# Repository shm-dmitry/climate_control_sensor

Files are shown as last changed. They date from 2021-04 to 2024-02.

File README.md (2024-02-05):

Project info
=======

*DEPRECATED. New board/fw project in https://github.com/shm-dmitry/air-detector*

This module allows you to control climate in room.

It reports:
- CO2 value
- Temperature
- Humidity
- Pressure
- PMx value
- Illumination
- Direction and speed of air in ventilation  

It controls:
- Exhaust fan 
- Cooling fan with speed control (fan_pwm driver) 
- Control any device (except Air Conditioneers at now) via IR
- TION Breather (in development at now...) via Bluetooth

Additional features:
- Integrates with any smart-house system via MQTT protocol (over WIFI)
- Contains touchpad supports multi-click (single click, double click, tripple click etc)
- Contains RGB led to indicate some internal state you want



Project status
=======

Schematics is done.
Board is done.

| Sensor | Software | Hardware |
| --- | --- | --- |
| TION 3S | In progress | - |
| BME280 | OK | OK |
| SGP30 | OK | OK |
| BH1750 | OK | OK |
| MH-Z19B | OK | OK |
| PMS7003 | OK | OK |
| Internal ESP32 Touch Pin | OK | OK |
| RGB Led | OK | OK |
| FAN Switch control | OK | OK |
| FAN speed control | OK | OK |
| IR Transmitter | OK | OK |
| Anemometer | OK | OK |

Install guide
===========

Hardware:

1. Install EAGLE. Freeware version is OK: https://www.autodesk.com/products/eagle/free-download
2. Open board (lw_board.brd)
3. Generate CAM data and make order on any factory

Software
1. Install ESP-IDF SDK https://docs.espressif.com/projects/esp-idf/en/latest/esp32/get-started/index.html
2. Clone and open project. 
3. Open `sdkconfig` and setup project settings. You can enable or disable unused options in `Climate Control Configuration` menu.
4. Build and flash ESP32 Devkit

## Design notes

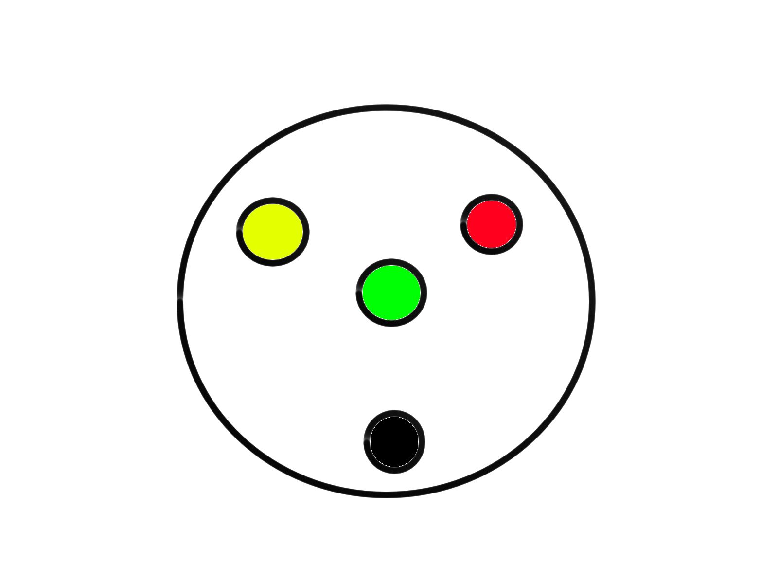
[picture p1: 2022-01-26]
anemometer_connector.jpg

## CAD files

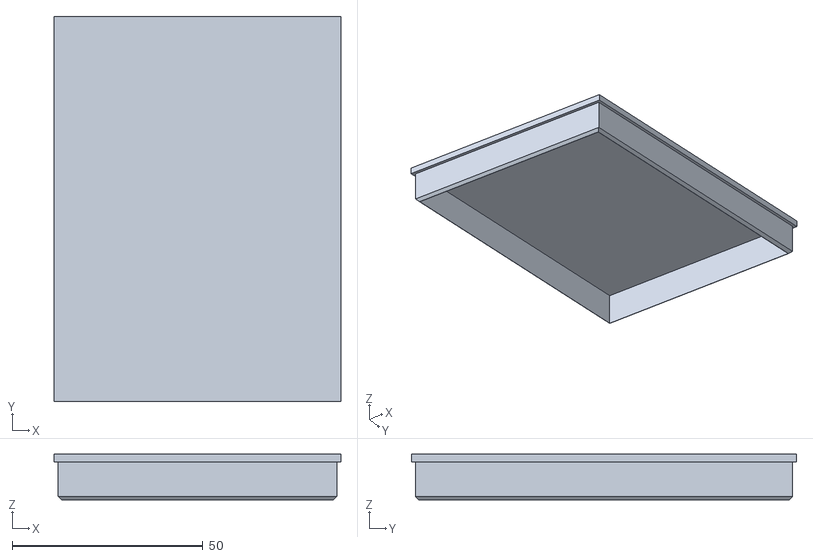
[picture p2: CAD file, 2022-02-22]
3d models/box-co2-hum-temp-tvoc-top.stl
75.2 x 101.0 x 12.0

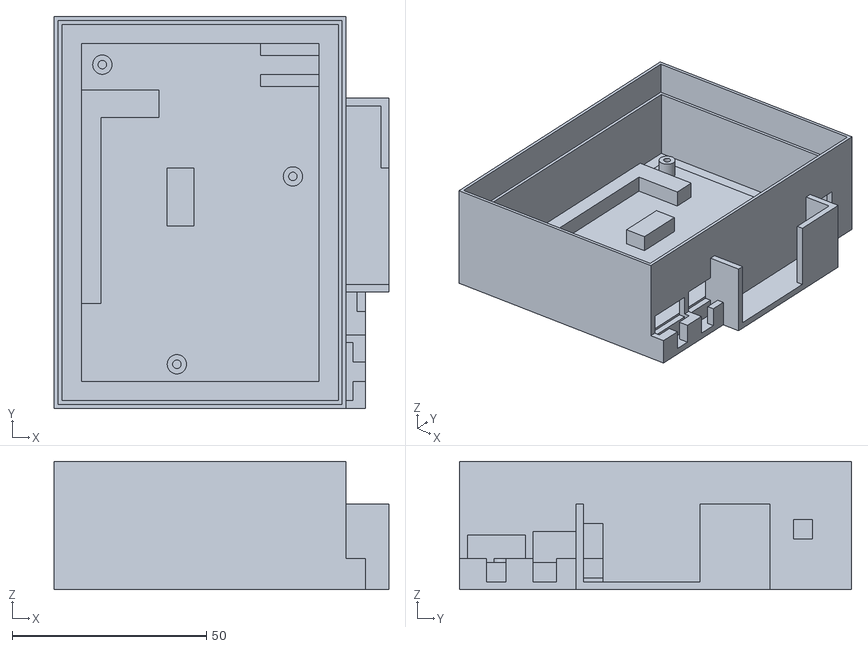
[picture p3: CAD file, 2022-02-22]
3d models/box-co2-hum-temp-tvoc-bottom.stl
86.2 x 101.0 x 33.0

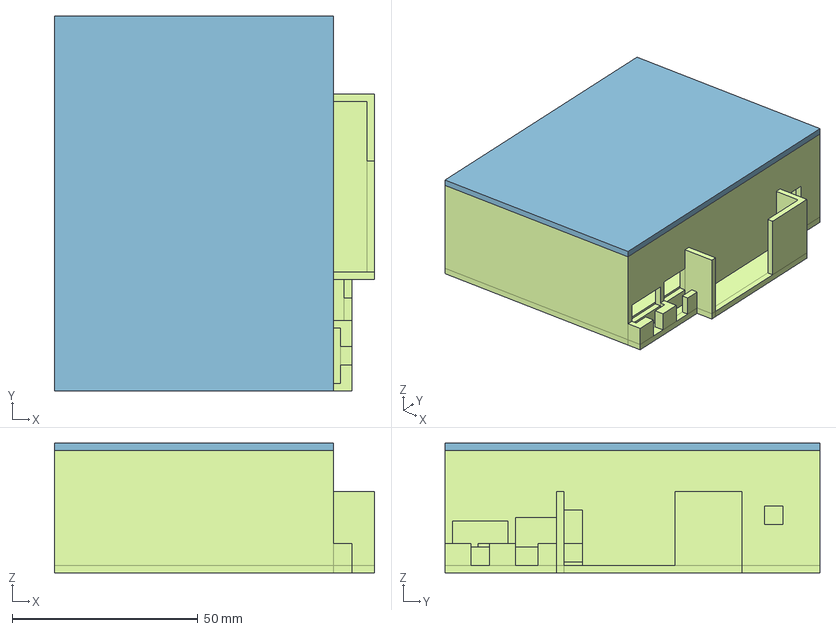
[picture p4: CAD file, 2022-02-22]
3d models/box-co2-hum-temp-tvoc.FCStd
86.2 x 101.0 x 35.0 mm
cup

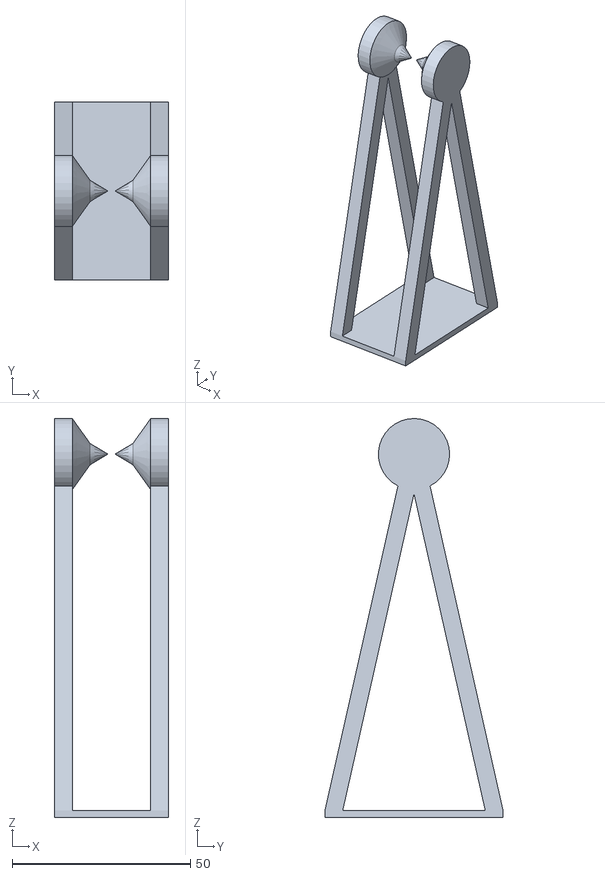
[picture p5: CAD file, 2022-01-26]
3d models/impeller-calibrate-tool.stl
32.0 x 50.0 x 112.0

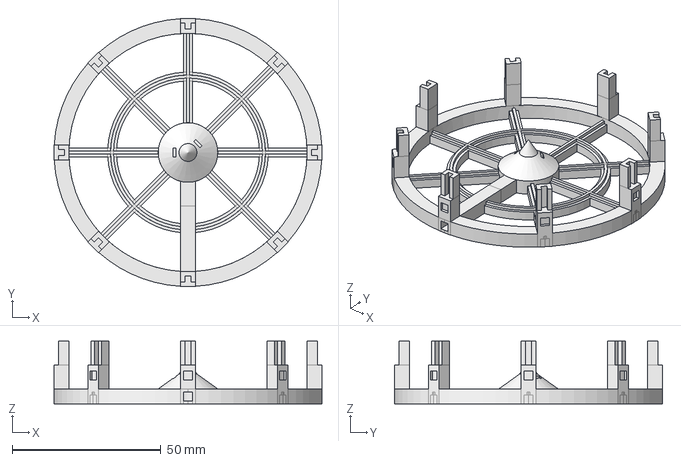
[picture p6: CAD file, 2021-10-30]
3d models/impeller-box-upside.FCStd
90.0 x 90.0 x 21.0 mm

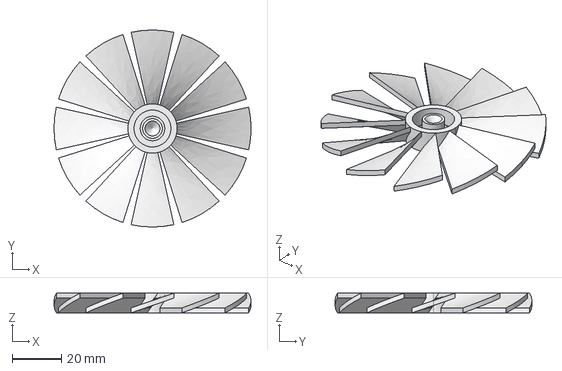
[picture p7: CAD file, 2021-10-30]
3d models/impeller.FCStd
80.0 x 80.0 x 8.00 mm

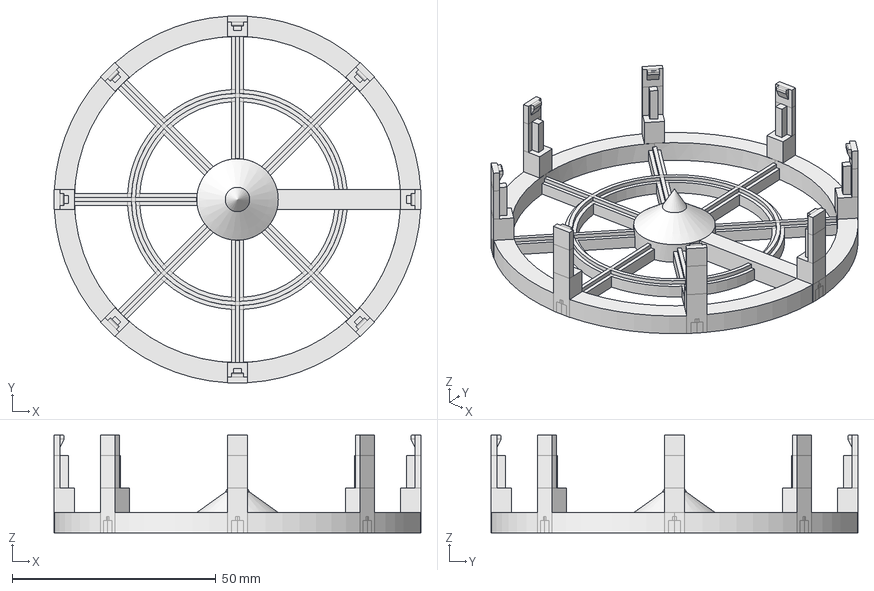
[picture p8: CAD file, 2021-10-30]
3d models/impeller-box-downside.FCStd
90.0 x 90.0 x 24.0 mm

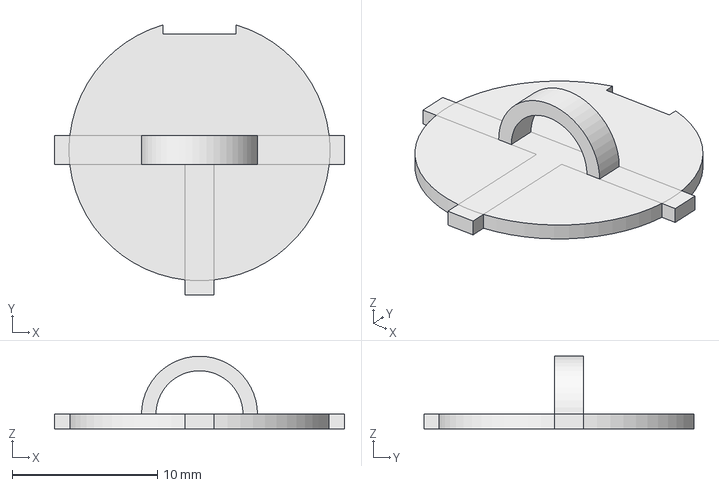
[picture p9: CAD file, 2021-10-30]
3d models/impeller-box-upside-cup.FCStd
20.0 x 18.6 x 5.00 mm

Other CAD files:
3d models/impeller-balancing-tool.FCStd
3d models/impeller-box-downside.stl
3d models/impeller-box-upside-cup.stl
3d models/impeller-box-upside.stl
3d models/impeller.stl

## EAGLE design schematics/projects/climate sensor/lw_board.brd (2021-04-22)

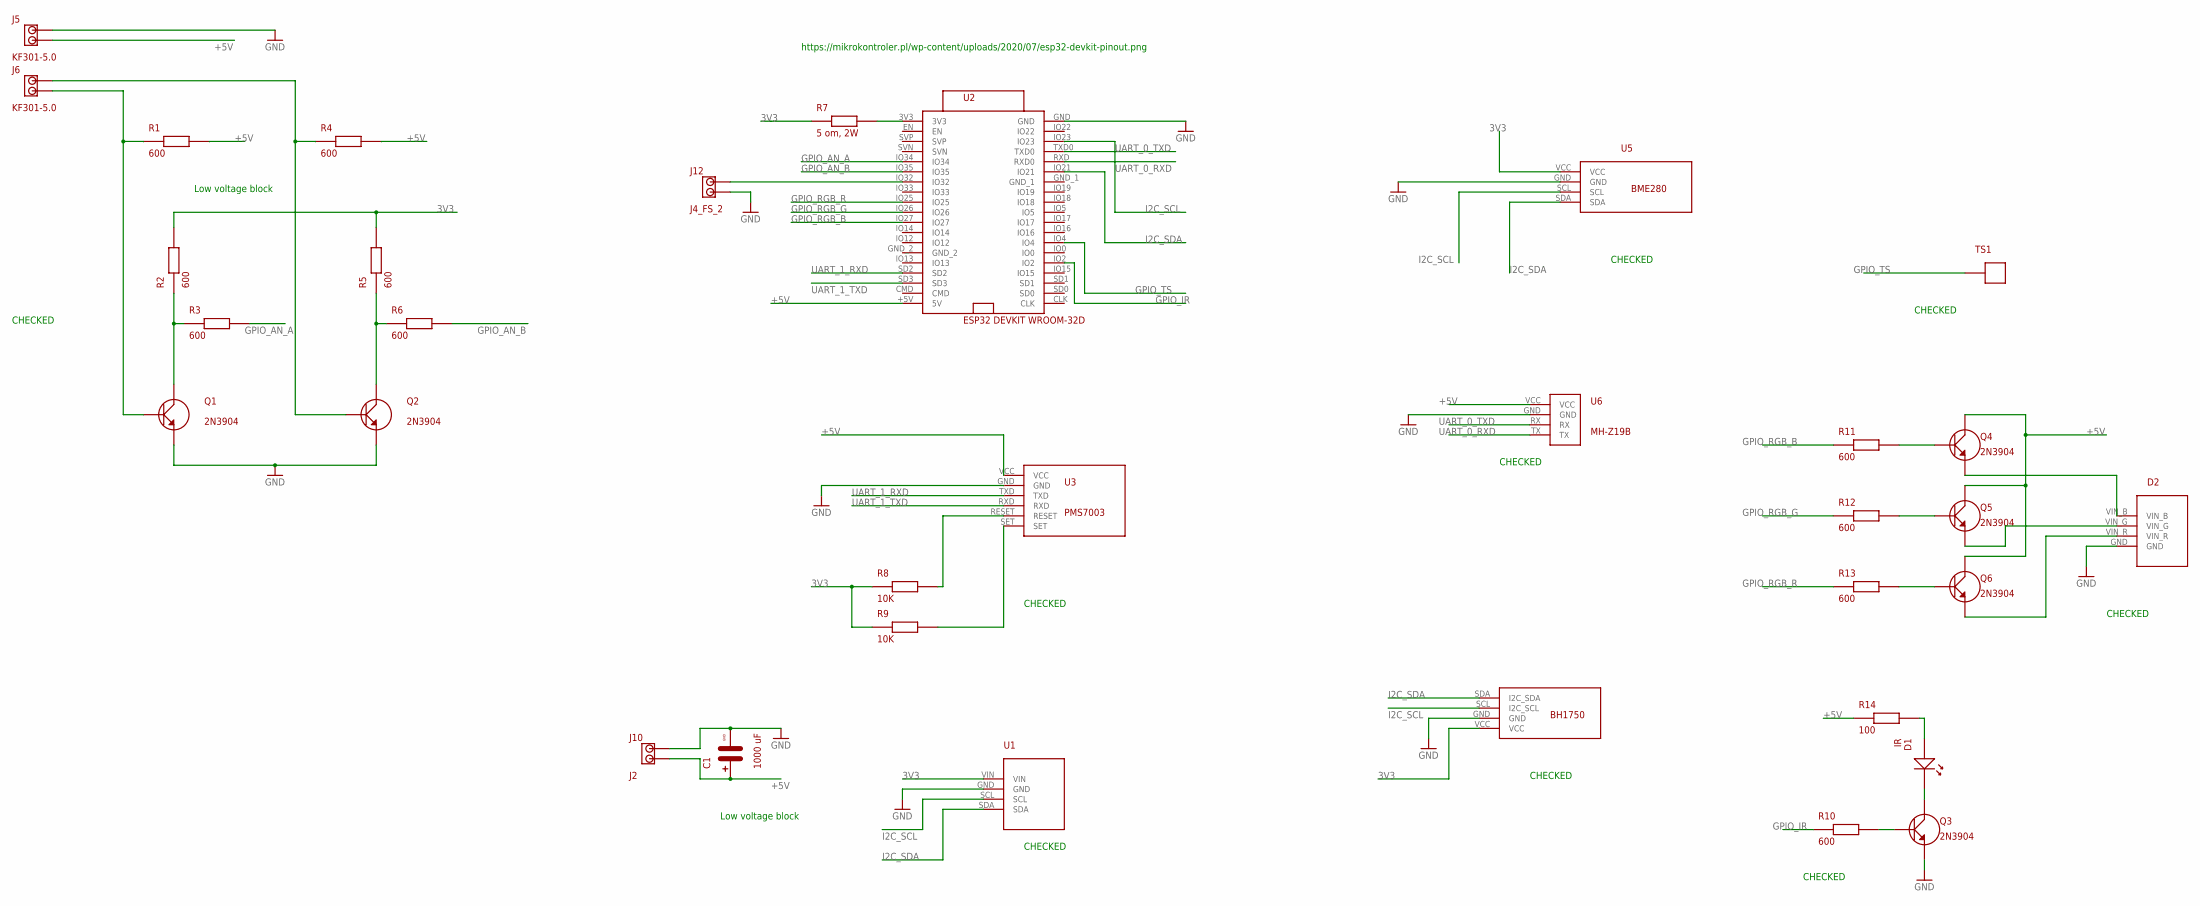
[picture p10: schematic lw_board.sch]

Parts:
C1: 1000 uF; C
D1: IR; LD
D2: RGBLED
J5, J6: KF301-5.0; J2
J10: J2
J12: J4_FS_2; J2
Q1, Q2, Q3, Q4, Q5, Q6: 2N3904; TRANSISTOR
R1, R2, R3, R4, R5, R6, R10, R11, R12, R13: 600; R
R7: 5 om, 2W; R
R8, R9: 10K; R
R14: 100; R
TS1: TOUCH_SENSOR
U1: GY-SGP30
U2: ESP32 DEVKIT WROOM-32D; ESP32
U3: PMS7003; PMS7003_J
U4: BH1750
U5: BME280
U6: MH_Z19B

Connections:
3V3: R2.P$2, R5.P$2, R7.P$1, R8.P$1, R9.P$1, U1.VIN, U4.VCC, U5.VCC
+5V: C1.PIN_PLUS, J5.PIN_2, J10.PIN_2, Q4.C, Q5.C, Q6.C, R1.P$2, R4.P$2, R14.P$1, U2.+5V (5V), U3.VCC, U6.VCC
GND: C1.PIN_GND, D2.GND, J5.PIN_1, J10.PIN_1, J12.PIN_2, Q1.E, Q2.E, Q3.E, U1.GND, U2.GND, U3.GND, U4.GND, U5.GND, U6.GND
GPIO_AN_A: R3.P$2, U2.IO34
GPIO_AN_B: R6.P$2, U2.IO35
GPIO_IR: R10.P$1, U2.IO2
GPIO_RGB_B: R11.P$1, U2.IO27
GPIO_RGB_G: R12.P$1, U2.IO26
GPIO_RGB_R: R13.P$1, U2.IO25
GPIO_TS: TS1.P$1, U2.IO4
I2C_SCL: U1.SCL, U2.IO23, U4.SCL (I2C_SCL), U5.SCL
I2C_SDA: U1.SDA, U2.IO21, U4.SDA (I2C_SDA), U5.SDA
unnamed: D2.VIN_B, Q4.E
unnamed: D2.VIN_G, Q5.E
unnamed: D2.VIN_R, Q6.E
unnamed: J6.PIN_1, Q2.B, R4.P$1
unnamed: J6.PIN_2, Q1.B, R1.P$1
unnamed: Q1.C, R2.P$1, R3.P$1
unnamed: Q2.C, R5.P$1, R6.P$1
unnamed: R8.P$2, U3.RESET
unnamed: J12.PIN_1, U2.IO32
unnamed: Q4.B, R11.P$2
unnamed: Q5.B, R12.P$2
unnamed: Q6.B, R13.P$2
unnamed: R7.P$2, U2.3V3
unnamed: D1.PIN_ANODE, Q3.C
unnamed: D1.PIN_CATHODE, R14.P$2
unnamed: Q3.B, R10.P$2
unnamed: R9.P$2, U3.SET
UART_0_RXD: U2.RXD (RXD0), U6.TX
UART_0_TXD: U2.TXD0, U6.RX
UART_1_RXD: U2.SD2, U3.TXD
UART_1_TXD: U2.SD3, U3.RXD

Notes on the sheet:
https://mikrokontroler.pl/wp-content/uploads/2020/07/esp32-devkit-pinout.png
CHECKED
Low voltage block

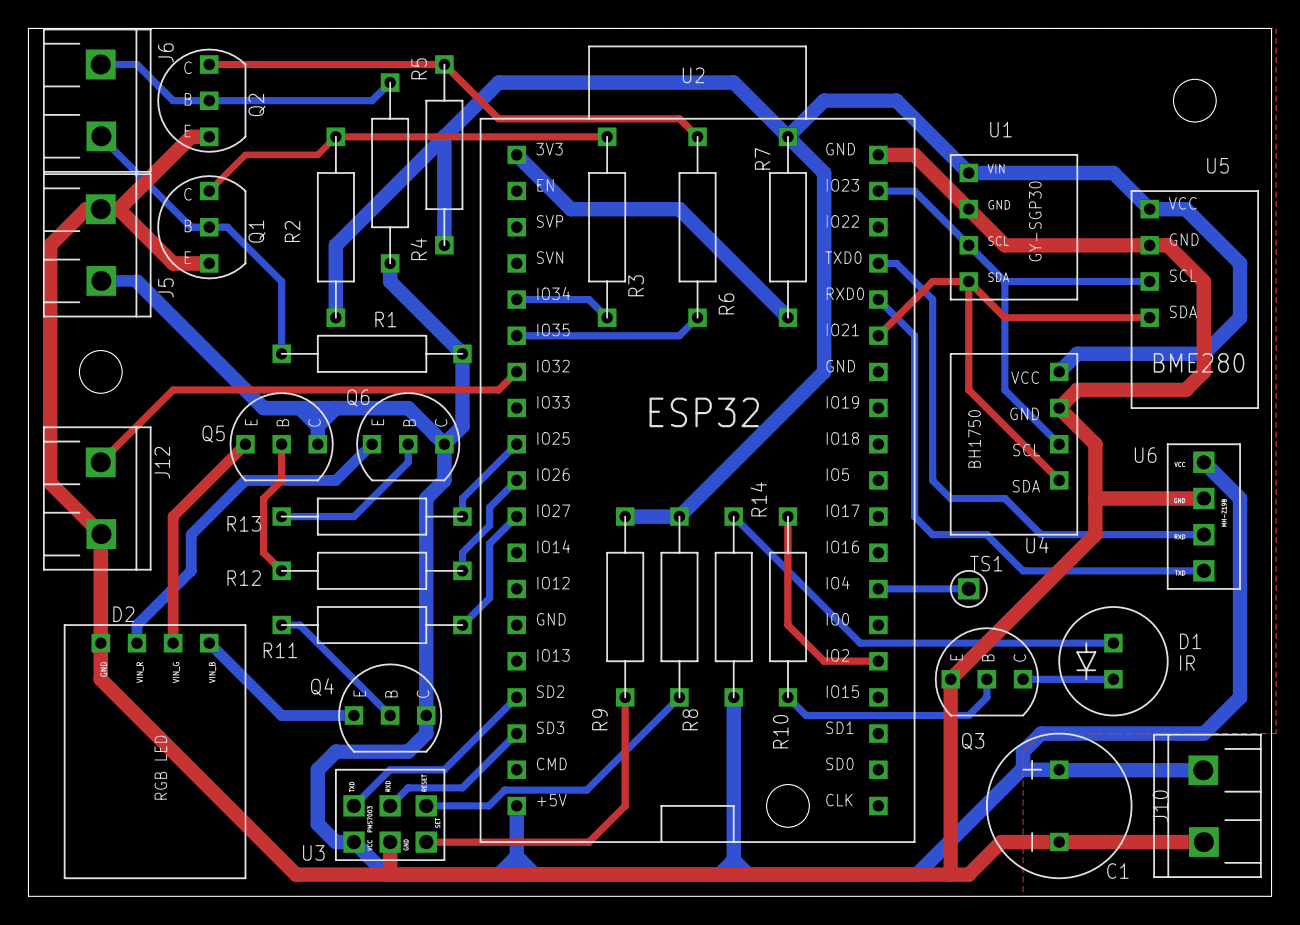
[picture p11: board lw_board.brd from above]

Board: 2 copper layers, 87.3 x 61.0 mm, 34 parts (0 on the bottom side), 33 nets.

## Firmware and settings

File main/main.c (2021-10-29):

#include "log.h"

#include "unistd.h"

#include "tion/tion.h"
#include "init/init.h"
#include "init/mqtt.h"
#include "init/init_logger.h"
#include "init/mqtt_logger.h"
#include "i2c/bme280/bme280.h"
#include "i2c/sgp30/sgp30.h"
#include "i2c/bh1750/bh1750.h"
#include "i2c/i2c_impl.h"
#include "uart/mh_z19b/mh_z19b.h"
#include "uart/pms7003/pms7003.h"
#include "gpio/rgbled/rgbled.h"
#include "gpio/fan/fan.h"
#include "gpio/fan_pwm/fan_pwm.h"
#include "gpio/anemometer/anemometer.h"
#include "gpio/touchpad/touchpad.h"
#include "gpio/ir/ir.h"

void app_main(void)
{
#if CONFIG_MQTT_INIT_LOGGER_ENABLED
	mqtt_logger_start();
#endif

#if CONFIG_MQTT_INIT_LOGGER_ENABLED
	init_logger_enable();
#endif

	init_flash();
	init_wifi(CONFIG_WIFI_SSID, CONFIG_WIFI_PASSWORD, CONFIG_WIFI_TOPIC);
	init_snmp();

#if CONFIG_I2C_PORT_0_ENABLED
	i2c_register_port(I2C_NUM_0, CONFIG_I2C_PORT_0_GPIO_SDA, CONFIG_I2C_PORT_0_GPIO_SCL);
#endif
#if CONFIG_I2C_PORT_1_ENABLED
	i2c_register_port(I2C_NUM_1, CONFIG_I2C_PORT_1_GPIO_SDA, CONFIG_I2C_PORT_1_GPIO_SCL);
#endif


#if CONFIG_TION_ENABLED
	tion_startup(CONFIG_TION_MQTT_TOPIC_STATUS, CONFIG_TION_MQTT_TOPIC_COMMANDS);
#endif

#if CONFIG_BME280_ENABLED
	bme280_init(CONFIG_BME280_PORT, CONFIG_BME280_TOPIC_STATUS);
#endif

#if CONFIG_SGP30_ENABLED
	sgp30_init(CONFIG_SGP30_PORT, CONFIG_SGP30_TOPIC_STATUS, CONFIG_SGP30_TOPIC_COMMAND);
#endif

#if CONFIG_SGP30_APPLI_COMPENSATION
	sgp30_init_auto_compensation();
#endif

#if CONFIG_BH1750_ENABLED
	bh1750_init(CONFIG_BH1750_PORT, CONFIG_BH1750_TOPIC_STATUS);
#endif

#if CONFIG_PMS7003_ENABLED
	uart_config_def_t pms7003_config = {
		.port = CONFIG_PMS7003_UART_PORT,
		.baud_rate = 9600,
		.pin_rxd = CONFIG_PMS7003_UART_PIN_RXD,
		.pin_txd = CONFIG_PMS7003_UART_PIN_TXD
	};

	pms7003_init(&pms7003_config, CONFIG_PMS7003_MQTT_TOPIC_STATUS);
#endif

#if CONFIG_MH_Z19B_ENABLED
	uart_config_def_t mh_z19b_config = {
		.port = CONFIG_MH_Z19B_UART_PORT,
		.baud_rate = 9600,
		.pin_rxd = CONFIG_MH_Z19B_UART_PIN_RXD,
		.pin_txd = CONFIG_MH_Z19B_UART_PIN_TXD
	};

	mh_z19b_init(&mh_z19b_config, CONFIG_MH_Z19B_MQTT_TOPIC_STATUS, CONFIG_MH_Z19B_MQTT_TOPIC_COMMAND);
#endif

#if CONFIG_RGBLED_ENABLED
	rgbled_config_t rgbled_config = {
		.gpio_red = CONFIG_RGBLED_GPIO_RED,
		.gpio_green = CONFIG_RGBLED_GPIO_GREEN,
		.gpio_blue = CONFIG_RGBLED_GPIO_BLUE,
	};

	rgbled_startup(&rgbled_config, CONFIG_RGBLED_MQTT_TOPIC_COMMAND);
#endif

#if CONFIG_FAN_ENABLED
	fan_startup(CONFIG_FAN_GPIO, CONFIG_FAN_MQTT_TOPIC_COMMAND, CONFIG_FAN_MQTT_TOPIC_STATUS);
#endif

#if CONFIG_FAN_PWM_ENABLED
	fan_pwm_startup(CONFIG_FAN_PWM_GPIO, CONFIG_FAN_PWM_MQTT_TOPIC_COMMAND);
#endif

#if CONFIG_ANEMOMETER_ENABLED
	anemometer_startup(CONFIG_ANEMOMETER_GPIO_A, CONFIG_ANEMOMETER_GPIO_B, CONFIG_ANEMOMETER_MQTT_TOPIC_STATUS, CONFIG_ANEMOMETER_MQTT_TOPIC_COMMAND);
#endif

#if CONFIG_TOUCH_ENABLED
	touchpad_init(CONFIG_TOUCH_PIN, CONFIG_TOUCH_MQTT_TOPIC_STATUS);
#endif

#if CONFIG_IR_ENABLED
	ir_startup(CONFIG_IR_GPIO, CONFIG_IR_MQTT_TOPIC_COMMAND);
#endif

	mqtt_start();

#if CONFIG_MQTT_INIT_LOGGER_ENABLED
	init_logger_dump_messages(CONFIG_MQTT_INIT_LOGGER_TOPIC);
#endif

	while(true) {
		vTaskDelay(100 / portTICK_PERIOD_MS);
	}
}

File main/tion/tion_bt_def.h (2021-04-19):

#ifndef MAIN_TION_TION_BT_DEF_H_
#define MAIN_TION_TION_BT_DEF_H_

#include "esp_gattc_api.h"
#include "esp_gap_ble_api.h"

#define TION_EXEC_TIMEOUT 60 // seconds

#define PROFILE_APP_ID 0

static const char TION_DEVICE_NAME[] = "Tion Breezer 3S";

struct gattc_profile_inst {
	uint16_t gattc_if;
	uint16_t conn_id;
	uint16_t service_start_handle;
	uint16_t service_end_handle;
	esp_bd_addr_t remote_bda;

	uint16_t read_handle;
	uint16_t write_handle;
	uint16_t pair_handle;
};

#define TION_EXEC_COMMAND_PAIR 0
#define TION_EXEC_COMMAND_REQUEST_DATA 1
#define TION_EXEC_COMMAND_WAIT_TION_STATUS 2
#define TION_EXEC_COMMAND_WRITE_DATA 3

typedef struct tion_exec_command_t {
	uint8_t commands[10];
	uint8_t commands_size;
	uint8_t current_command;

	time_t started;

	tion_change_status_t new_status;
	tion_status_t * current_status;

	uint8_t retry_allowed_count;

	uint8_t command_uuid;
} tion_exec_command_t;

static esp_ble_scan_params_t ble_scan_params = {
		.scan_type = BLE_SCAN_TYPE_ACTIVE,
		.own_addr_type = BLE_ADDR_TYPE_PUBLIC,
		.scan_filter_policy = BLE_SCAN_FILTER_ALLOW_ALL,
		.scan_interval = 0x50,
		.scan_window = 0x30 };

static esp_bt_uuid_t tion_remote_service_uuid = {
// 6e400001-b5a3-f393-e0a9-e50e24dcca9e
		.len = ESP_UUID_LEN_128,
		.uuid = {
				.uuid128 = { 0x9e, 0xca, 0xdc, 0x24, 0x0e, 0xe5, 0xa9, 0xe0, 0x93, 0xf3, 0xa3, 0xb5, 0x01, 0x00, 0x40, 0x6e }
		},
};

 static esp_bt_uuid_t tion_remote_characteristics_write_uuid = {
 // 6e400002-b5a3-f393-e0a9-e50e24dcca9e
	 .len = ESP_UUID_LEN_128,
	 .uuid = {
			 .uuid128 = { 0x9e, 0xca, 0xdc, 0x24, 0x0e, 0xe5, 0xa9, 0xe0, 0x93, 0xf3, 0xa3, 0xb5, 0x02, 0x00, 0x40, 0x6e }
	 },
 };

static esp_bt_uuid_t tion_remote_characteristics_read_uuid = {
// 6e400003-b5a3-f393-e0a9-e50e24dcca9e
		.len = ESP_UUID_LEN_128,
		.uuid = {
				.uuid128 = { 0x9e, 0xca, 0xdc, 0x24, 0x0e, 0xe5, 0xa9, 0xe0, 0x93, 0xf3, 0xa3, 0xb5, 0x03, 0x00, 0x40, 0x6e }
		},
};


#endif /* MAIN_TION_TION_BT_DEF_H_ */

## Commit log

2021-02-18 EAGLE schematics for this project with local component library
    [bath_room_cabel_and_fan_block.sch, bath_room_high_voltage_block.sch, bath_room_low_voltage_block.sch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]
2021-02-18 pin numbers synchronized with schematics
2021-02-18 added eagle board files for low-voltage schemas
    [bath_room_cabel_and_fan_block.sch, bath_room_low_voltage_block.brd, bath_room_low_voltage_block.sch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]
2021-02-18 changes in board files.
    [bath_room_low_voltage_block.brd, room_1.brd]
2021-03-24 actualized schematics
    [bath_room_low_voltage_block.brd, full_schema.sch, room_1.brd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]
2021-03-24 added IR interface
    [full_schema.sch]
2021-03-24 added buildin touch sensor, maybe I will use it.
    [bath_room_cabel_and_fan_block.sch, bath_room_high_voltage_block.sch, bath_room_low_voltage_block.brd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]
2021-03-29 Custom partiton mapping
    [partitions.csv]
2021-03-30 CO2 sensor works now.
    [full_schema.sch]
2021-03-30 Corrected schematics for PMS7003
    [full_schema.sch]
2021-03-30 touchpad integration (not tested yet)
    [full_schema.sch]
2021-03-30 touchpad works, but I have to work with hardware to detect action on some distance from sensor
2021-03-31 Removed TTP223 integration. Removed TTP223 from schematics Added logs to FAN integration (prepare for upcoming debug)
    [full_schema.sch]
2021-04-01 touchpad driver: added on_cliock event fan_switch: tested and worked.
    [full_schema.sch]
2021-04-01 Start working on anemometer driver
    [full_schema.sch]
2021-04-01 anemometer - driver works
2021-04-01 anemometer hardware works
    [full_schema.sch]
2021-04-01 Added and tested IR transmitter functionality
    [full_schema.sch]
2021-04-02 Prepare library and schematics to create board
    [anemometer.sch, full_schema.sch]
2021-04-02 Continue prepare schematics to create board
    [anemometer.sch, full_schema.sch]
2021-04-02 rgbled checked and works
    [full_schema.sch]
2021-04-02 Added low-voltage-block schema First version of low-voltage-block board
    [full_schema.sch, lw_board.brd, lw_board.sch]
2021-04-03 continue work with board
    [lw_board.brd]
2021-04-03 rename elements, optimize board
    [full_schema.sch, lw_board.brd, lw_board.sch]
2021-04-03 Board is DONE
    [lw_board.brd, lw_board.sch]
2021-04-06 add RGB LED calibration
2021-04-06 change argument in ledc_fade_func_install (it was mistake)
2021-04-11 Work under I2C bus. BME280 - tested BH1750 - tested
2021-04-11 SGP30 sensor works now. I2C bus fully tested.
    [full_schema.sch, lw_board.brd, lw_board.sch]
2021-04-11 rename threads
2021-04-19 1. mqtt - fix memory allocation in subscribe method. 2. logs - rename LOG define 3. tion - working under TION integration module
    [i2c_impl.c, tion_bt_def.h]
2021-04-20 Working under TION driver. BT restarts successfully on error. Timeout checker works fine. Some code refactoring.
    [tion_bt_command.h]
2021-04-22 Fixed issues in board.
    I received board from jlcpcb
    This commit fixed issues in board:
    1. drill size increased - it was too small for some components.
    2. 'J2' component in library was re-drawed using sizes from datasheet
    3. Textes for J2 component was increased in size and moved to bPlace
    layer (bottom layer). On top layer not enougth space for it.
    4. Increased minimum size for routes.
    5. Added 3 holes
    6. Re-routed some places - some routes moved to bottom layer.
    [full_schema.sch, lw_board.brd, lw_board.sch]
2021-04-26 wifi: ability to change AP sensor connected to.
    WIFI Connector listens for a message in MQTT topic with new
    SSID/PASSWORD.
    After receiving message it saves credentials in NVS and restarts.
    On 'boot' process sensor tryed to connect to WiFi AP
    1. using saved credentials if exists
    2. using configured credentials if saved credentials absent or AP
    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
2021-05-06 I assembled device and it worked!
    [full_schema.sch]
2021-05-09 Added ability to recalibrate SGP30 sensor (on hot-replace for example to another module)
    [full_schema.sch]
2021-05-28 Commit schematics for a window control project
    [full_schema.sch]
2021-05-28 Changed some nomanals during making order
    [anemometer.sch, full_schema.sch]
2021-07-02 added fan_pwm driver
    [full_schema.sch]
2021-07-04 FAN PWM speed control - updated driver and schematics. Driver tested on RQD2510LS fan and its worked on 30...100% speed
    [full_schema.sch]
2021-07-07 MH-Z19B start producing wrong data... Trying to find reason..
    [anemometer.c, bh1750.c, bme280.c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]
2021-07-08 I have problem with MH-Z19B sensor. I think problem with auto-calibration witch auto-executed after one day warks. So 1. Added real-time logging to MQTT 2. During startup added READ operation witch c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
    [main.c]
2021-07-19 move window-control schema to separete project
    [full_schema.sch]
2021-07-19 fix some logging mistakes
    [fan_pwm_api.c]
2021-08-20 1. changed FAN_PWM driver 2. added default values to Kconfig.projbuild
2021-10-29 fixes in touchpad sensor
    [full_schema.sch]
2021-10-30 Added 3D models for anemometer
    [impeller-balancing-tool.FCStd, impeller-box-downside.FCStd, impeller-box-upside-cup.FCStd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]
2022-01-26 Added 3D model box for CO2 / Humidity / Temperature / TVOC sensors configuration
    [box-co2-hum-temp-tvoc-bottom.stl, box-co2-hum-temp-tvoc-top.stl, box-co2-hum-temp-tvoc.FCStd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]
2022-02-22 Changed box 3D model
    [box-co2-hum-temp-tvoc-bottom.stl, box-co2-hum-temp-tvoc-top.stl, box-co2-hum-temp-tvoc.FCStd]
